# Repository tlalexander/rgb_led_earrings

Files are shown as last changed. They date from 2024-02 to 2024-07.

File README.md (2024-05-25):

# rgb_led_earrings

CAD:
https://cad.onshape.com/documents/09024334f2a397aa5bc58e5a/w/46f4970e419c9b5834fa8bd0/e/3dd3a53ca6818e1934df52f5

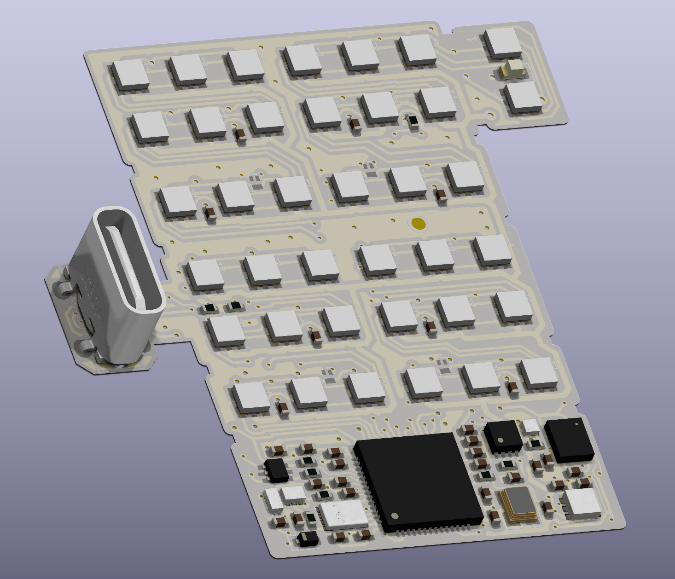
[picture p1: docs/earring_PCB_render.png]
a render of the front of the PCB

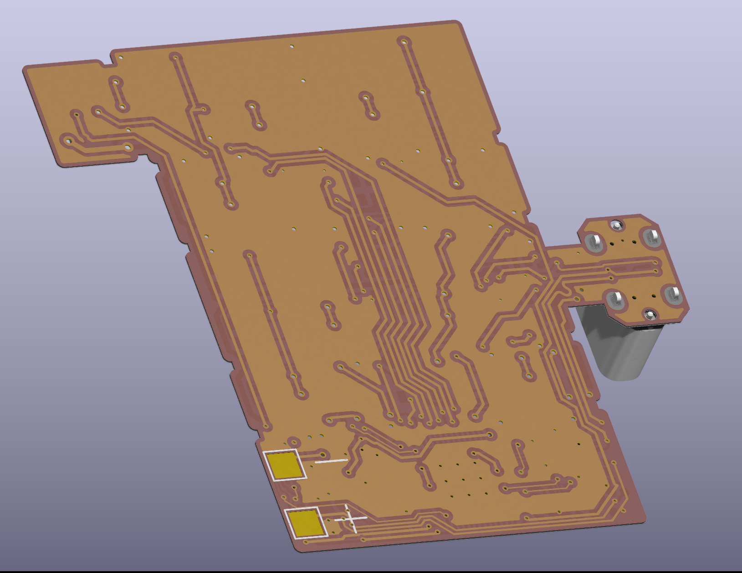
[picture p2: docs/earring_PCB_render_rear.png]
a render of the rear of the PCB


A gentle glow shines from your direction.
A twist, a step, a shimmy.
You move with freedom in your space.
Today is a good day. <3

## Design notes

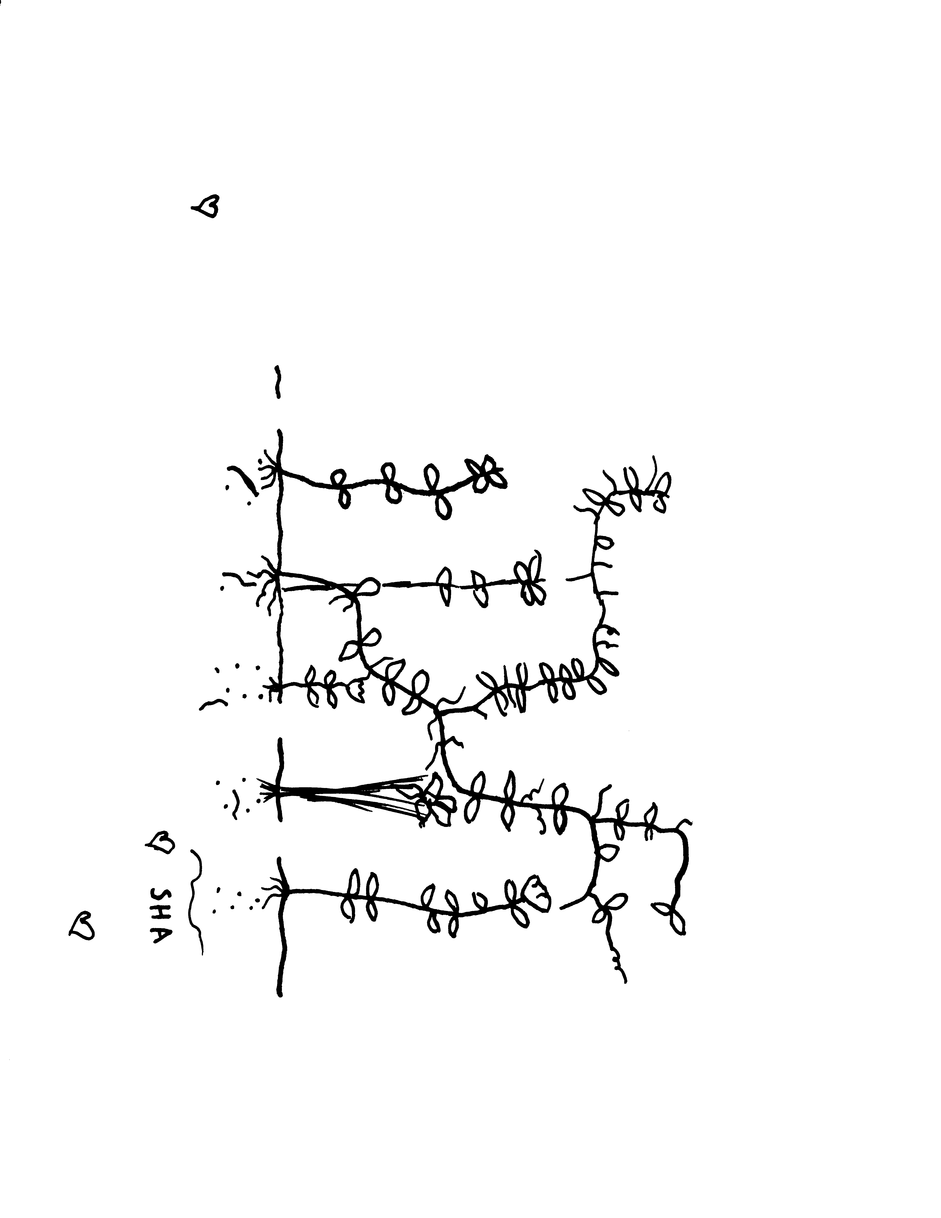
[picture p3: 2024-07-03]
docs/mask_clean_up.png

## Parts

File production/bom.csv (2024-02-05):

Designator | Footprint | Quantity | Value | LCSC Part #
C1, C11, C13, C14, C15, C16, C17, C18, C19, C22, C23, C24, C4, C8, C9 | 0402 | 15 | 100n | C30926
C10, C12, C20, C25, C26, C27, C28, C29, C30, C31, C32 | 0402 | 11 | 1u | C15849
C2, C21, C3, C7 | 0402 | 4 | 10u | C15850
C5, C6 | 0402 | 2 | 20p | C1648
D2 | D_SOD-523 | 1 | D | C4468063
J2 | USB-C-TH_GT-USB-7055 | 1 | USB_C_Receptacle_USB2.0 | C2686963
Q1, Q2, Q3, Q4 | Diodes_DFN1006-3 | 4 | NMOS 20V 0.75A 500mΩ@4.5V | C504098
R1, R5 | 0402 | 2 | 1.1k | C325543
R10 | 0402 | 1 | ~
R2 | 0402 | 1 | 100k | C60491
R3, R4 | 0402 | 2 | 5.1k | C137955
R6, R7 | 0402 | 2 | 27 | C138021
R9 | 0402 | 1 | 510 | C137860
U1 | DFN1608-3_L1.5-W0.8-P0.42-BL-EP | 1 | Magnetic Switch | C879626
U10 | SOT-666 | 1 | USBLC6-2P6 | C2827693
U11, U12, U13, U14, U15, U16, U17, U18, U19, U21, U22, U24, U25, U26, U27, U28, U29, U30, U31, U32, U33, U34, U35, U36, U37, U38, U39, U40, U41, U42, U45, U46, U47, U48, U49, U5, U50, U52 | LED-SK9822-EC20 | 38 | ~
U20 | DFN-8-1EP_2x2mm_P0.5mm_EP0.9x1.5mm | 1 | LGS4056H | C5124109
U3 | RP2040-QFN-56 | 1 | RP2040 | C2040
U4 | IC_W25Q16JVUXIQ_TR | 1 | W25Q16JV | C2843335
U6 | UFDFN-6_1.45x1mm | 1 | Buffer | C7598681
U7 | LGA-14_3x2.5mm_P0.5mm_LayoutBorder3x4y | 1 | LSM6DS3 | C2829074
U8 | DFN1x1 | 1 | ~ | C5884119
U9 | WDFN-6-2x2 | 1 | ~
Y1 | Crystal_SMD_2520-4Pin_2.5x2.0mm | 1 | Crystal_GND24 | C284155

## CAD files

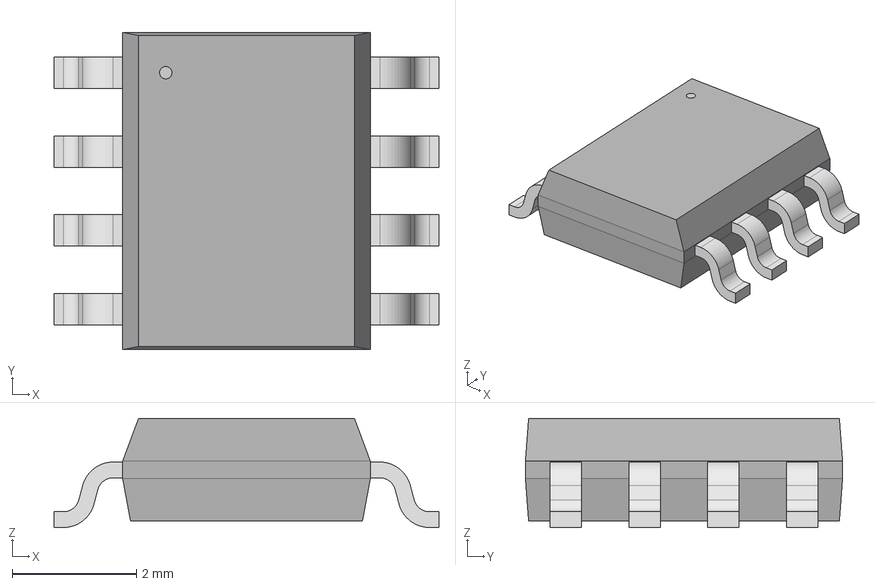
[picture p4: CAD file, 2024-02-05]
parts/2022-10-21_22-39-45/STEP/SOP8SOIC-8_UMW.step
6.20 x 5.11 x 1.75 mm

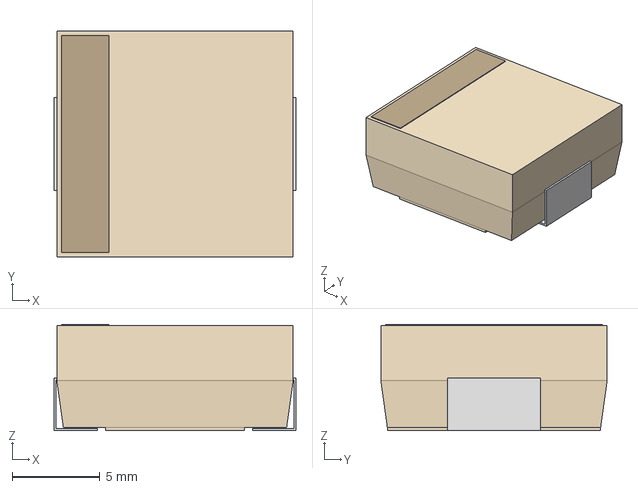
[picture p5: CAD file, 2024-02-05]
parts/2022-11-05_07-16-47/STEP/IND_MWSA1206S_SNL.step
13.8 x 12.9 x 6.04 mm

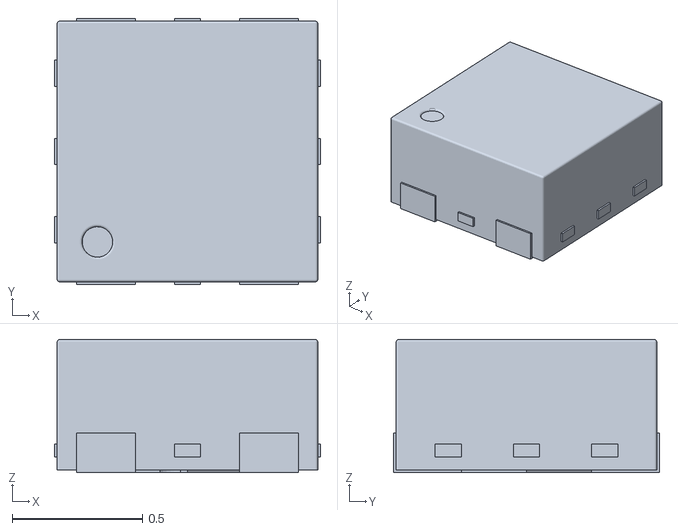
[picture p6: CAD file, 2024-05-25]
parts/DFN-4_L1.0-W1.0-P0.65-BL-EP.obj
1.02 x 1.02 x 0.51

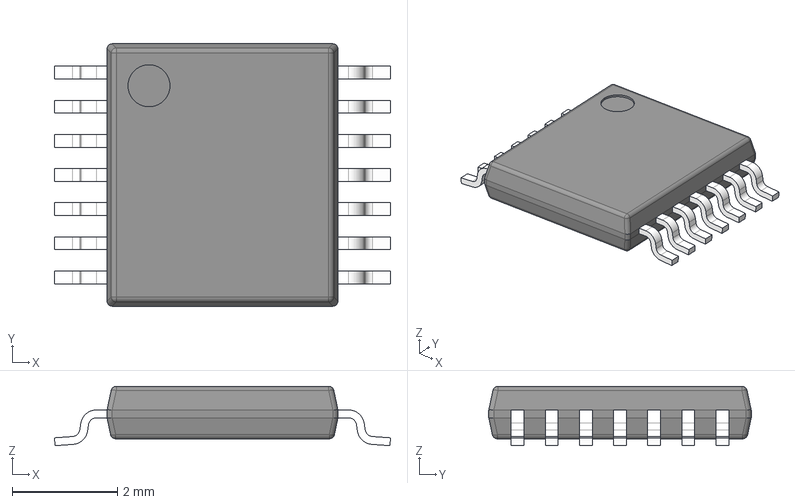
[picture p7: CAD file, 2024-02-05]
parts/STEP/PW0014A.stp
6.40 x 5.00 x 1.13 mm
BODY-TSSOP
LEAD-TSSOP x 14
PIN1

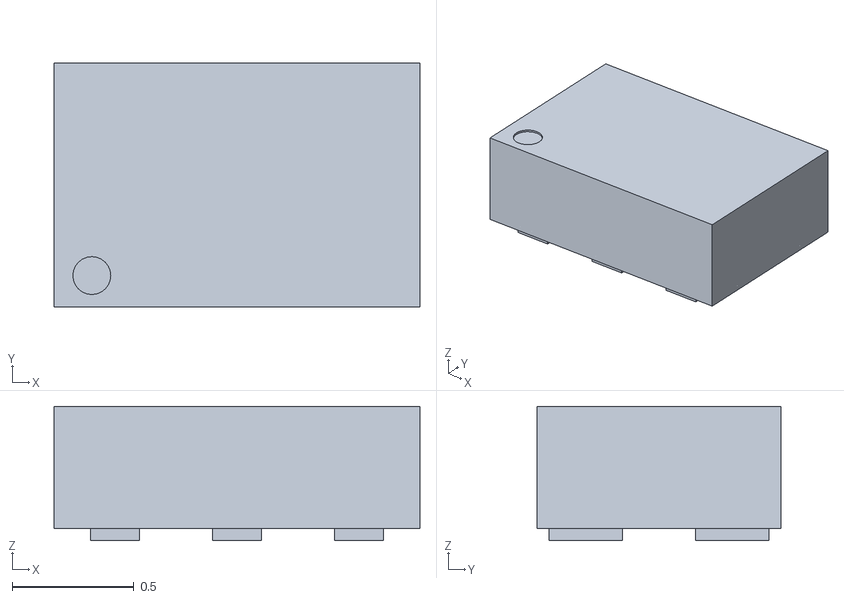
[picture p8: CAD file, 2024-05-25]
parts/SON-6_L1.5-W1.0-P0.50-BL_TI_DRY.obj
1.50 x 1.00 x 0.55

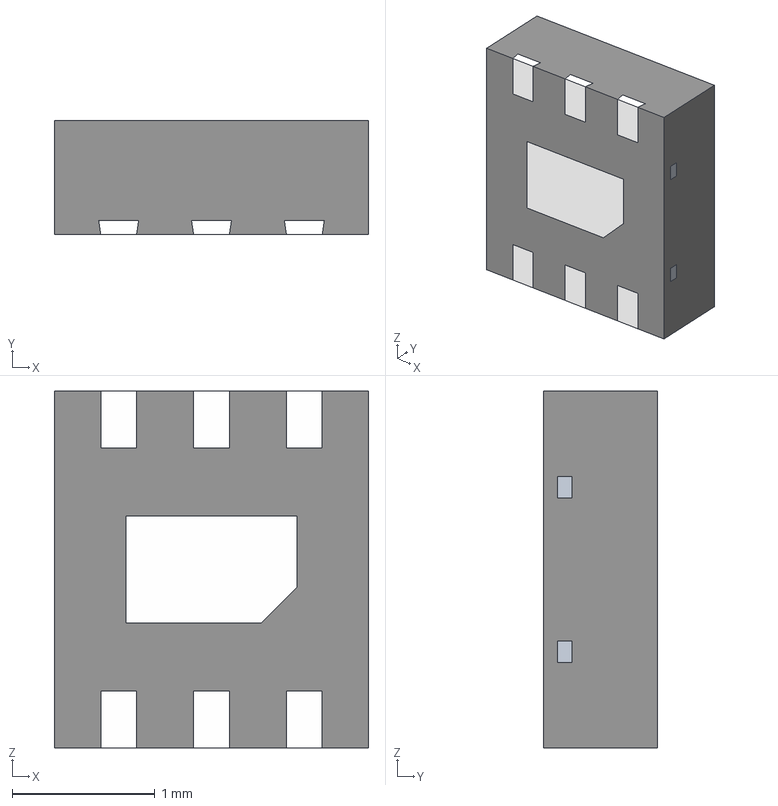
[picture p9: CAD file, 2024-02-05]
parts/STEP/NGF0006A.stp
2.20 x 0.8 x 2.50 mm
BODY_SDB06A_48
MANIFOLD_SOLID_BREP_1871
MANIFOLD_SOLID_BREP_2022
MANIFOLD_SOLID_BREP_2173
MANIFOLD_SOLID_BREP_2324
MANIFOLD_SOLID_BREP_2475
MANIFOLD_SOLID_BREP_2626
MANIFOLD_SOLID_BREP_2777
MANIFOLD_SOLID_BREP_2928
MANIFOLD_SOLID_BREP_3079
MANIFOLD_SOLID_BREP_3230
MANIFOLD_SOLID_BREP_3414

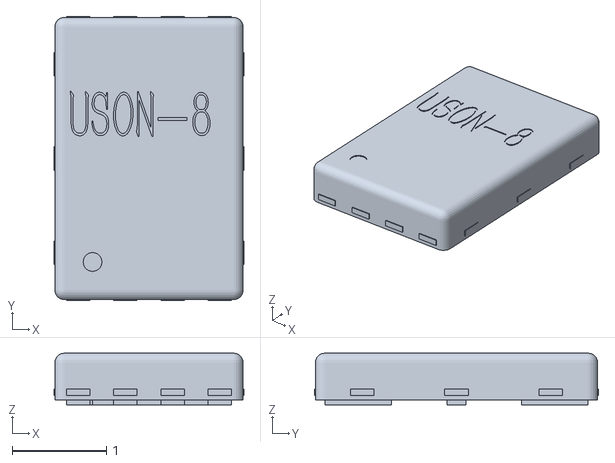
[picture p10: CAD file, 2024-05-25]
parts/USON-8_L3.0-W2.0-P0.50-BL-EP.obj
2.02 x 3.02 x 0.55

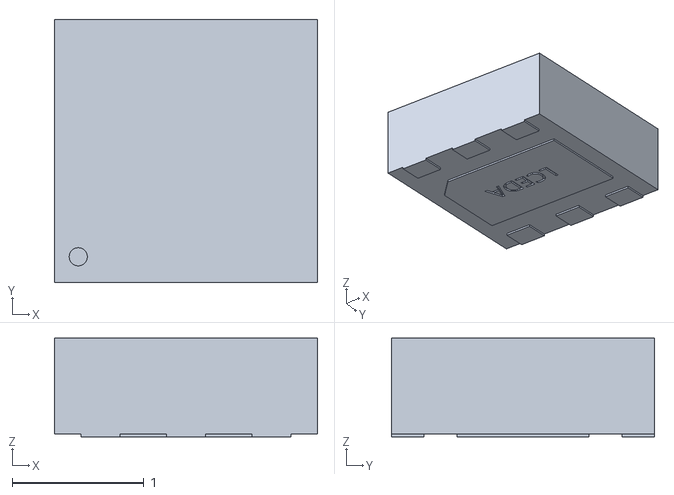
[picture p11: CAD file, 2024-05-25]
parts/WDFN-6_L2.0-W2.0-P0.65-BL-EP-1.obj
2.00 x 2.00 x 0.75

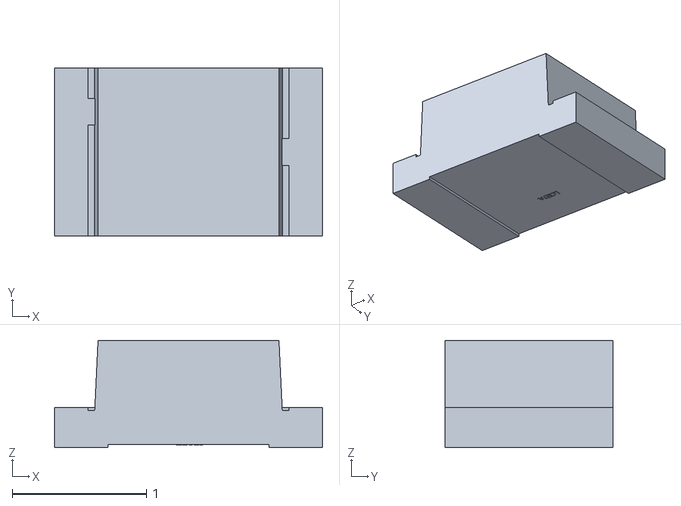
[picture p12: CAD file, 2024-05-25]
parts/OPTO-SMD_SFH3710-Z.obj
2.00 x 1.25 x 0.8

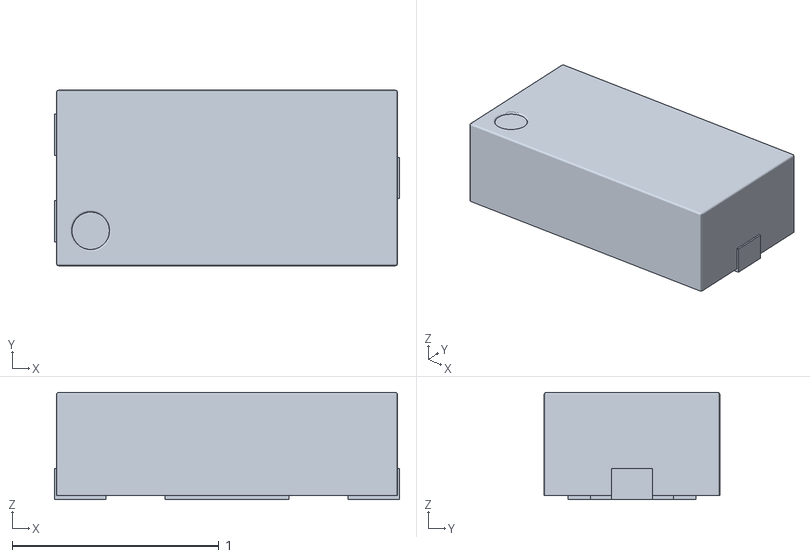
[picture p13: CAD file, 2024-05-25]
parts/DFN1608-3_L1.5-W0.8-P0.42-BL-EP.obj
1.67 x 0.85 x 0.52

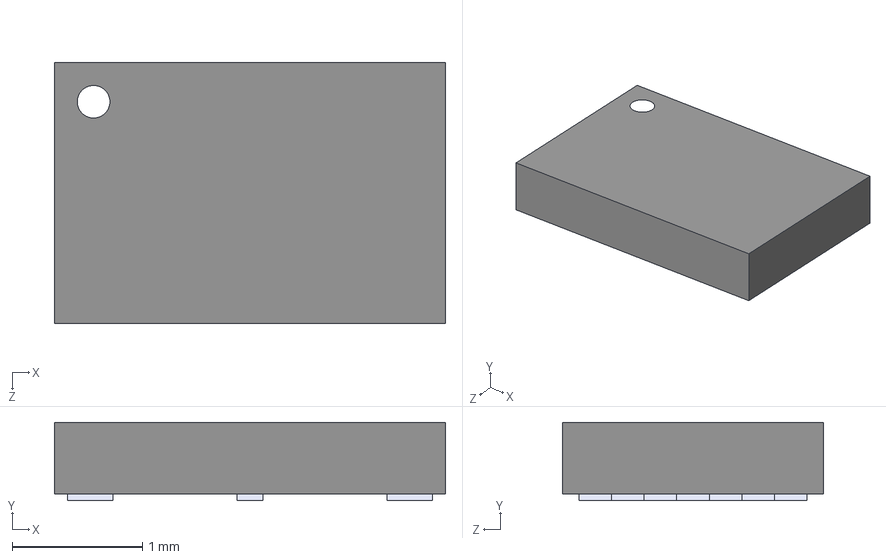
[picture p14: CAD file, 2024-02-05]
parts/W25Q16JVUXIQ_TR.step
3.00 x 0.6 x 2.00 mm

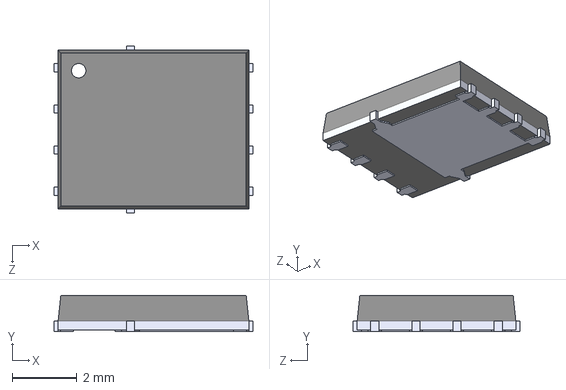
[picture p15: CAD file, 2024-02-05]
parts/PowerPAK-SO8.STEP
6.15 x 1.12 x 5.16 mm

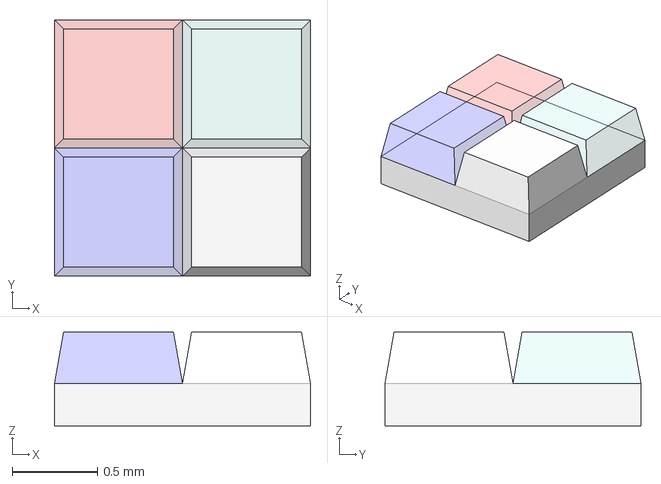
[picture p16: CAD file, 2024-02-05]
parts/sk6812_1.5x1.5mm.step
1.50 x 1.50 x 0.55 mm

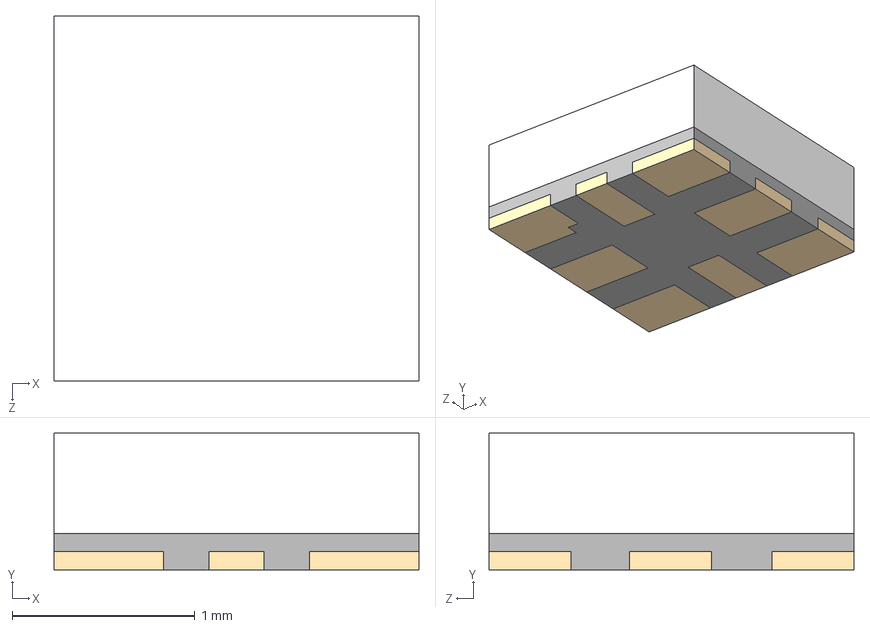
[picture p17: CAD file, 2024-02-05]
parts/APA-102-2020-256-8.STEP
2.00 x 0.75 x 2.00 mm

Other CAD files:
parts/sk6812_opaque.step
parts/DWV0008A.stp
parts/earring_pcb - Flat pattern of pcb.dxf
parts/USB4125-GF-A-0190--3DModel-STEP-56544.STEP
parts/5556416-1.stp
parts/STEP/DWV0008A.stp
parts/USB-C-TH_GT-USB-7055.obj
parts/WDFN-6-2x2.step
parts/sk6812_1.5x1.5_freecad.step

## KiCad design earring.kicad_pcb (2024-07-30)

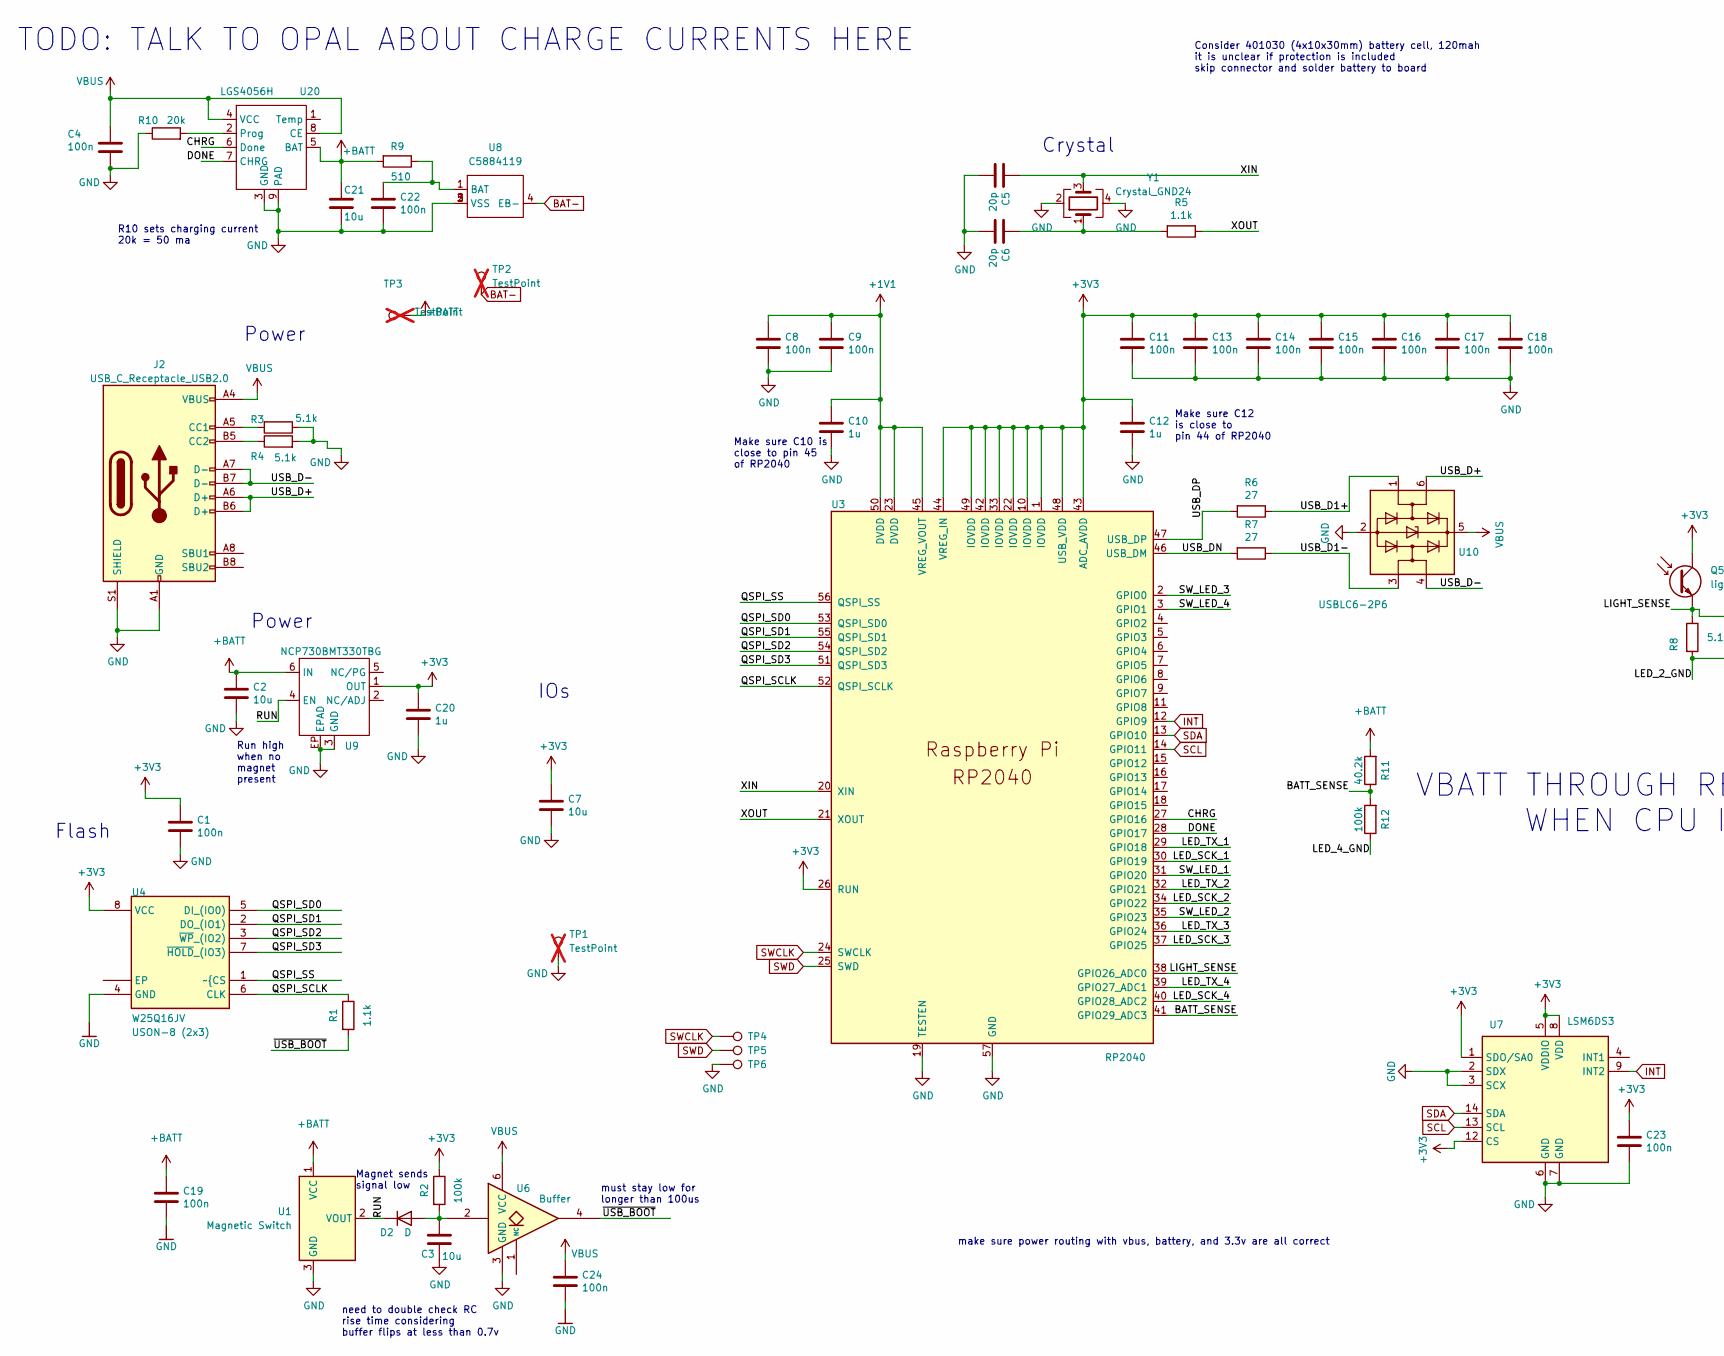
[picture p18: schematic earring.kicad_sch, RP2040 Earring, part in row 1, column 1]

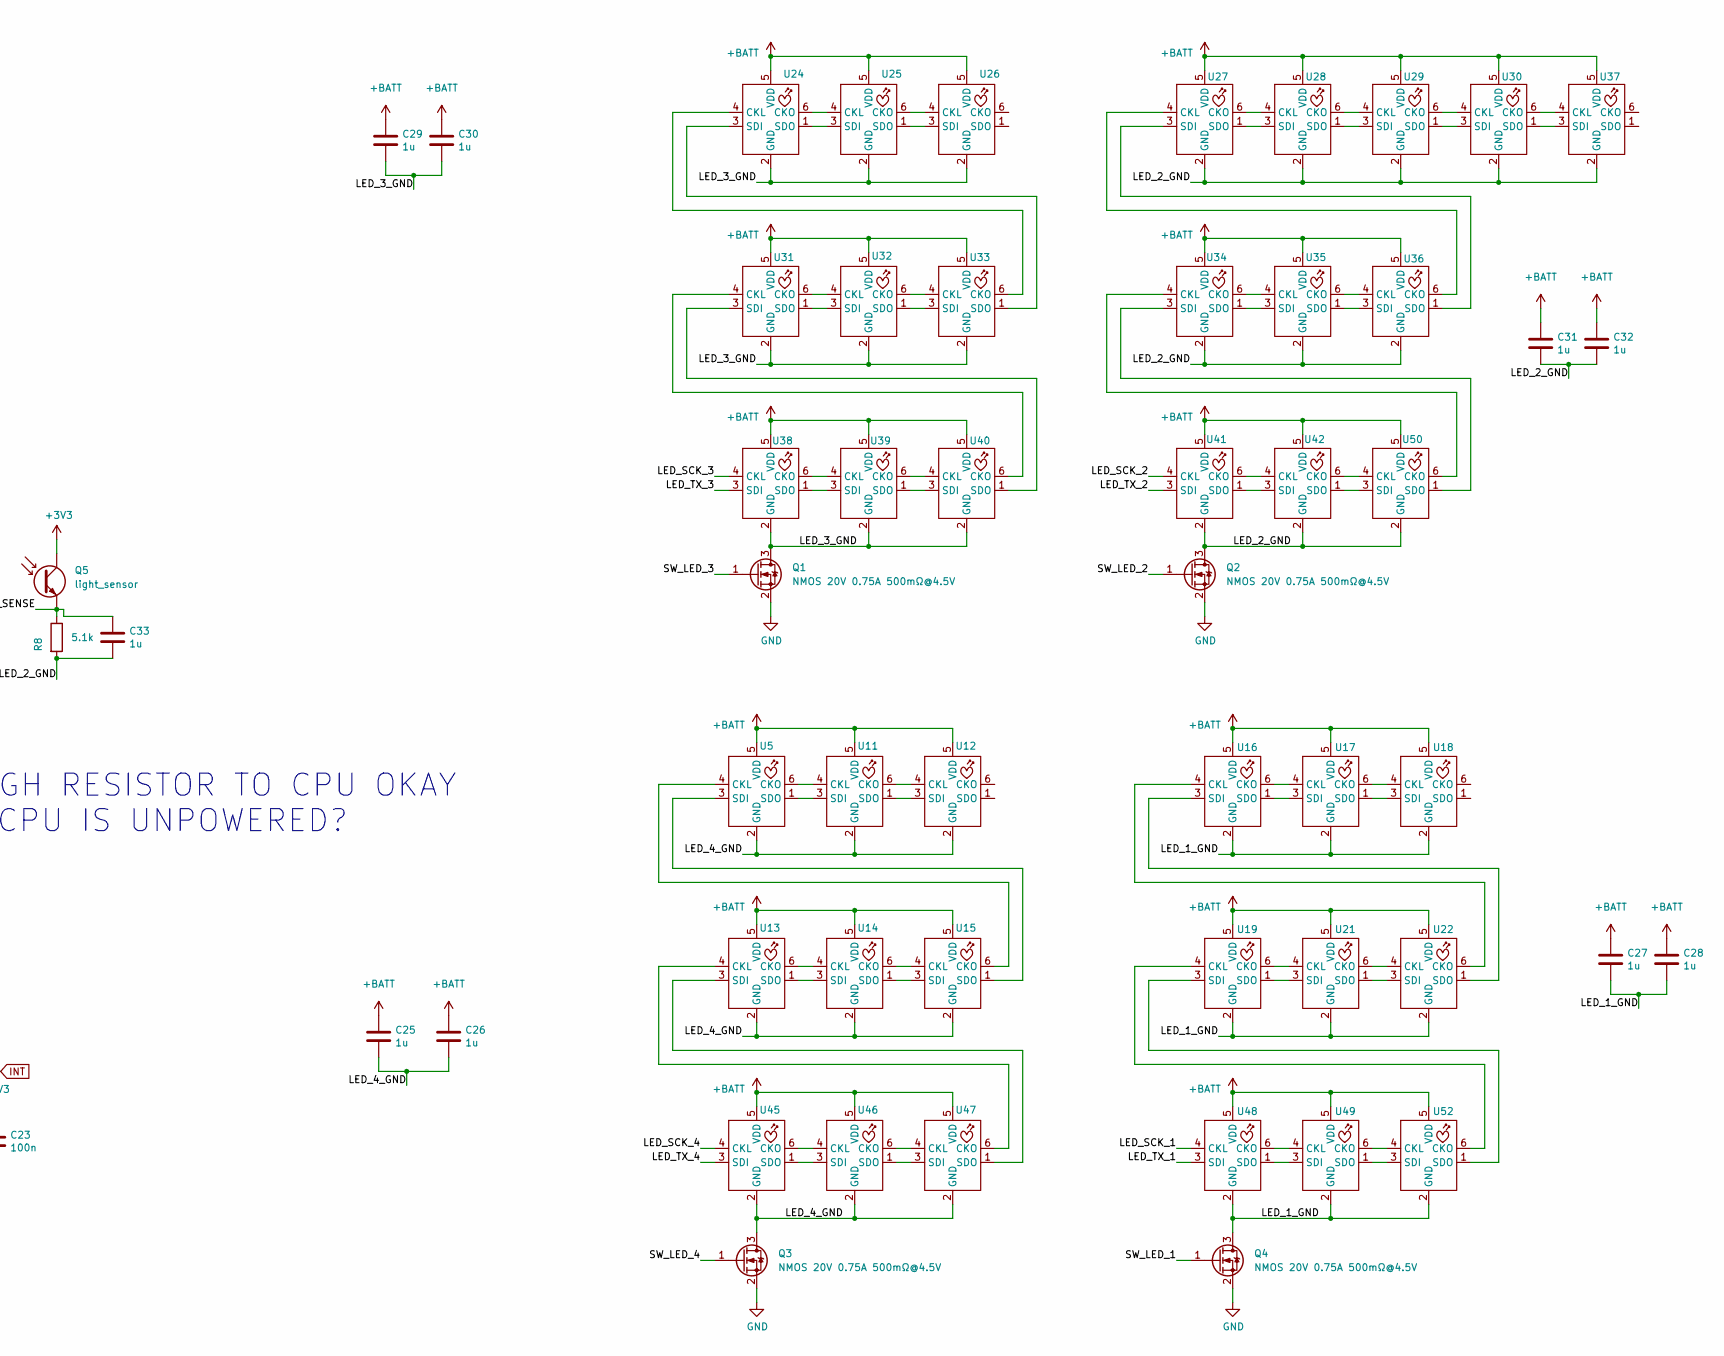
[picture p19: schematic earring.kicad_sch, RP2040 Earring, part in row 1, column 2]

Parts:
C1, C4, C8, C9, C11, C13, C14, C15, C16, C17, C18, C19, C22, C23, C24: 100n; C_0402_1005Metric; LCSC C60474
C2, C3, C7, C21: 10u; C_0402_1005Metric; LCSC C315248
C5, C6: 20p; C_0402_1005Metric; LCSC C107000
C10, C12, C20, C25, C26, C27, C28, C29, C30, C31, C32, C33: 1u; C_0402_1005Metric; LCSC C29266
D2: D; D_SOD-523; LCSC C4468063
J2: USB_C_Receptacle_USB2.0; USB-C-TH_GT-USB-7055; LCSC C2686963
Q1, Q2, Q3, Q4: NMOS 20V 0.75A 500mΩ@4.5V; Diodes_DFN1006-3; LCSC C504098
Q5: light_sensor; LED_0603_1608Metric; LCSC C146233
R1, R5: 1.1k; R_0402_1005Metric; LCSC C325543
R2, R12: 100k; R_0402_1005Metric; LCSC C60491
R3, R4, R8: 5.1k; R_0402_1005Metric; LCSC C25905
R6, R7: 27; R_0402_1005Metric; LCSC C138021
R9: 510; R_0402_1005Metric; LCSC C137860
R10: 20k; R_0402_1005Metric; LCSC C25765
R11: 40.2k; R_0402_1005Metric; LCSC C25893
TP1: TestPoint; TestPoint_Pad_D1.0mm; LCSC C238130; not fitted
TP2, TP3: TestPoint; TestPoint_Pad_2.0x2.0mm; LCSC C238130; not fitted
TP4, TP5, TP6: TestPoint; TestPoint_Pad_1.0x1.0mm
U1: Magnetic Switch; DFN1608-3_L1.5-W0.8-P0.42-BL-EP; LCSC C879626
U3: RP2040; RP2040-QFN-56; LCSC C2040
U4: W25Q16JV; IC_W25Q16JVUXIQ_TR; MPN W25Q16JVUXIQ; LCSC C2843335
U5, U11, U12, U13, U14, U15, U16, U17, U18, U19, U21, U22, U25, U26, U27, U28, U29, U30, U31, U32, U33, U34, U35, U36, U37, U38, U39, U40, U41, U42, U45, U46, U47, U48, U49, U50, U52: LED-SK9822-EC20
U6: Buffer; UFDFN-6_1.45x1mm; LCSC C2864615
U7: LSM6DS3; LGA-14_3x2.5mm_P0.5mm_LayoutBorder3x4y; LCSC C2829074
U8: DFN1x1; LCSC C5884119
U9: NCP730BMT330TBG; WDFN-6-2x2; LCSC C892821
U10: USBLC6-2P6; SOT-666; LCSC C2827693
U20: LGS4056H; DFN-8-1EP_2x2mm_P0.5mm_EP0.9x1.5mm; LCSC C5124109
U24: SK9822-EC20; LED-SK9822-EC20
Y1: Crystal_GND24; Crystal_SMD_2520-4Pin_2.5x2.0mm; LCSC C284155

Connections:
+1V1: C8.1, C9.1, C10.1, U3.23 (DVDD), U3.45 (VREG_VOUT), U3.50 (DVDD)
+3V3: C1.1, C7.1, C11.1, C12.1, C13.1, C14.1, C15.1, C16.1, C17.1, C18.1, C20.1, C23.1, Q5.1, R2.1, U3.1 (IOVDD), U3.10 (IOVDD), U3.22 (IOVDD), U3.26 (RUN), U3.33 (IOVDD), U3.42 (IOVDD), U3.43 (ADC_AVDD), U3.44 (VREG_IN), U3.48 (USB_VDD), U3.49 (IOVDD), U4.8 (VCC), U7.1 (SDO/SA0), U7.5 (VDDIO), U7.8 (VDD), U7.12 (CS), U9.1 (OUT)
+BATT: C2.1, C19.1, C21.1, C25.1, C26.1, C27.1, C28.1, C29.1, C30.1, C31.1, C32.1, R9.2, R11.2, TP3.1, U1.1 (VCC), U5.5 (VDD), U9.6 (IN), U11.5 (VDD), U12.5 (VDD), U13.5 (VDD), U14.5 (VDD), U15.5 (VDD), U16.5 (VDD), U17.5 (VDD), U18.5 (VDD), U19.5 (VDD), U20.5 (BAT), U21.5 (VDD), U22.5 (VDD), U24.5 (VDD), U25.5 (VDD), U26.5 (VDD), U27.5 (VDD), U28.5 (VDD), U29.5 (VDD), U30.5 (VDD), U31.5 (VDD), U32.5 (VDD), U33.5 (VDD), U34.5 (VDD), U35.5 (VDD), U36.5 (VDD), U37.5 (VDD), U38.5 (VDD), U39.5 (VDD), U40.5 (VDD), U41.5 (VDD), U42.5 (VDD), U45.5 (VDD), U46.5 (VDD), U47.5 (VDD), U48.5 (VDD), U49.5 (VDD), U50.5 (VDD), U52.5 (VDD)
/BATT_SENSE: R11.1, R12.2, U3.41 (GPIO29_ADC3)
/CHRG: U3.27 (GPIO16), U20.6 (Done)
/DONE: U3.28 (GPIO17), U20.7 (CHRG)
/LED_1_GND: C27.2, C28.2, Q4.3 (D), U16.2 (GND), U17.2 (GND), U18.2 (GND), U19.2 (GND), U21.2 (GND), U22.2 (GND), U48.2 (GND), U49.2 (GND), U52.2 (GND)
/LED_2_GND: C31.2, C32.2, C33.2, Q2.3 (D), R8.2, U27.2 (GND), U28.2 (GND), U29.2 (GND), U30.2 (GND), U34.2 (GND), U35.2 (GND), U36.2 (GND), U37.2 (GND), U41.2 (GND), U42.2 (GND), U50.2 (GND)
/LED_3_GND: C29.2, C30.2, Q1.3 (D), U24.2 (GND), U25.2 (GND), U26.2 (GND), U31.2 (GND), U32.2 (GND), U33.2 (GND), U38.2 (GND), U39.2 (GND), U40.2 (GND)
/LED_4_GND: C25.2, C26.2, Q3.3 (D), R12.1, U5.2 (GND), U11.2 (GND), U12.2 (GND), U13.2 (GND), U14.2 (GND), U15.2 (GND), U45.2 (GND), U46.2 (GND), U47.2 (GND)
/LED_SCK_1: U3.30 (GPIO19), U48.4 (CKL)
/LED_SCK_2: U3.34 (GPIO22), U41.4 (CKL)
/LED_SCK_3: U3.37 (GPIO25), U38.4 (CKL)
/LED_SCK_4: U3.40 (GPIO28_ADC2), U45.4 (CKL)
/LED_TX_1: U3.29 (GPIO18), U48.3 (SDI)
/LED_TX_2: U3.32 (GPIO21), U41.3 (SDI)
/LED_TX_3: U3.36 (GPIO24), U38.3 (SDI)
/LED_TX_4: U3.39 (GPIO27_ADC1), U45.3 (SDI)
/LIGHT_SENSE: C33.1, Q5.2, R8.1, U3.38 (GPIO26_ADC0)
/QSPI_SCLK: R1.1, U3.52 (QSPI_SCLK), U4.6 (CLK)
/QSPI_SD0: U3.53 (QSPI_SD0), U4.5 (DI_(IO0))
/QSPI_SD1: U3.55 (QSPI_SD1), U4.2 (DO_(IO1))
/QSPI_SD2: U3.54 (QSPI_SD2), U4.3 (~WP_(IO2))
/QSPI_SD3: U3.51 (QSPI_SD3), U4.7 (~HOLD_(IO3))
/QSPI_SS: U3.56 (QSPI_SS), U4.1 (~{CS)
/RUN: D2.1 (K), U1.2 (VOUT), U9.4 (EN)
/SW_LED_1: Q4.1 (G), U3.31 (GPIO20)
/SW_LED_2: Q2.1 (G), U3.35 (GPIO23)
/SW_LED_3: Q1.1 (G), U3.2 (GPIO0)
/SW_LED_4: Q3.1 (G), U3.3 (GPIO1)
/USB_D1+: R6.1, U10.1 (I/O1)
/USB_D1-: R7.1, U10.3 (I/O2)
/USB_D+: J2.A6 (D+), J2.B6 (D+), U10.6 (I/O1)
/USB_D-: J2.A7 (D-), J2.B7 (D-), U10.4 (I/O2)
/USB_DN: R7.2, U3.46 (USB_DM)
/USB_DP: R6.2, U3.47 (USB_DP)
/XIN: C5.1, U3.20 (XIN), Y1.3
/XOUT: R5.1, U3.21 (XOUT)
/~USB_BOOT: R1.2, U6.4
BAT-: TP2.1, U8.4 (EB-)
GND: C1.2, C2.2, C3.2, C4.2, C5.2, C6.2, C7.2, C8.2, C9.2, C10.2, C11.2, C12.2, C13.2, C14.2, C15.2, C16.2, C17.2, C18.2, C19.2, C20.2, C21.2, C22.2, C23.2, C24.2, J2.A1 (GND), J2.A12 (GND), J2.B1 (GND), J2.B12 (GND), J2.S1 (SHIELD), Q1.2 (S), Q2.2 (S), Q3.2 (S), Q4.2 (S), R3.1, R4.2, R10.1, TP1.1, TP6.1, U1.3 (GND), U3.19 (TESTEN), U3.57 (GND), U4.4 (GND), U6.3 (GND), U7.2 (SDX), U7.3 (SCX), U7.6 (GND), U7.7 (GND), U8.2 (VSS), U8.3 (VSS), U8.5 (VSS), U9.3 (GND), U9.EP (EPAD), U10.2 (GND), U20.3 (GND), U20.9 (PAD), Y1.2, Y1.4
INT: U3.12 (GPIO9), U7.9 (INT2)
unnamed: C6.1, R5.2, Y1.1
unnamed: C3.1, D2.2 (A), R2.2, U6.2
unnamed: J2.A5 (CC1), R3.2
unnamed: J2.B5 (CC2), R4.1
unnamed: C22.1, R9.1, U8.1 (BAT)
unnamed: U5.6 (CKO), U11.4 (CKL)
unnamed: U11.6 (CKO), U12.4 (CKL)
unnamed: U5.1 (SDO), U11.3 (SDI)
unnamed: U11.1 (SDO), U12.3 (SDI)
unnamed: U13.4 (CKL), U47.6 (CKO)
unnamed: U13.6 (CKO), U14.4 (CKL)
unnamed: U13.3 (SDI), U47.1 (SDO)
unnamed: U13.1 (SDO), U14.3 (SDI)
unnamed: U14.6 (CKO), U15.4 (CKL)
unnamed: U14.1 (SDO), U15.3 (SDI)
unnamed: U5.4 (CKL), U15.6 (CKO)
unnamed: U5.3 (SDI), U15.1 (SDO)
unnamed: U16.4 (CKL), U22.6 (CKO)
unnamed: U16.6 (CKO), U17.4 (CKL)
unnamed: U16.3 (SDI), U22.1 (SDO)
unnamed: U16.1 (SDO), U17.3 (SDI)
unnamed: U17.6 (CKO), U18.4 (CKL)
unnamed: U17.1 (SDO), U18.3 (SDI)
unnamed: U19.4 (CKL), U52.6 (CKO)
unnamed: U19.6 (CKO), U21.4 (CKL)
unnamed: U19.3 (SDI), U52.1 (SDO)
unnamed: U19.1 (SDO), U21.3 (SDI)
unnamed: R10.2, U20.2 (Prog)
unnamed: U21.6 (CKO), U22.4 (CKL)
unnamed: U21.1 (SDO), U22.3 (SDI)
unnamed: U24.4 (CKL), U33.6 (CKO)
unnamed: U24.6 (CKO), U25.4 (CKL)
unnamed: U24.3 (SDI), U33.1 (SDO)
unnamed: U24.1 (SDO), U25.3 (SDI)
unnamed: U25.6 (CKO), U26.4 (CKL)
unnamed: U25.1 (SDO), U26.3 (SDI)
unnamed: U27.4 (CKL), U36.6 (CKO)
unnamed: U27.6 (CKO), U28.4 (CKL)
unnamed: U27.3 (SDI), U36.1 (SDO)
unnamed: U27.1 (SDO), U28.3 (SDI)
unnamed: U28.6 (CKO), U29.4 (CKL)
unnamed: U28.1 (SDO), U29.3 (SDI)
unnamed: U29.6 (CKO), U30.4 (CKL)
unnamed: U29.1 (SDO), U30.3 (SDI)
unnamed: U30.6 (CKO), U37.4 (CKL)
unnamed: U30.1 (SDO), U37.3 (SDI)
unnamed: U31.4 (CKL), U40.6 (CKO)
unnamed: U31.6 (CKO), U32.4 (CKL)
unnamed: U31.3 (SDI), U40.1 (SDO)
unnamed: U31.1 (SDO), U32.3 (SDI)
unnamed: U32.6 (CKO), U33.4 (CKL)
unnamed: U32.1 (SDO), U33.3 (SDI)
unnamed: U34.4 (CKL), U50.6 (CKO)
unnamed: U34.6 (CKO), U35.4 (CKL)
unnamed: U34.3 (SDI), U50.1 (SDO)
unnamed: U34.1 (SDO), U35.3 (SDI)
unnamed: U35.6 (CKO), U36.4 (CKL)
unnamed: U35.1 (SDO), U36.3 (SDI)
unnamed: U38.6 (CKO), U39.4 (CKL)
unnamed: U38.1 (SDO), U39.3 (SDI)
unnamed: U39.6 (CKO), U40.4 (CKL)
unnamed: U39.1 (SDO), U40.3 (SDI)
unnamed: U41.6 (CKO), U42.4 (CKL)
unnamed: U41.1 (SDO), U42.3 (SDI)
unnamed: U42.6 (CKO), U50.4 (CKL)
unnamed: U42.1 (SDO), U50.3 (SDI)
unnamed: U45.6 (CKO), U46.4 (CKL)
unnamed: U45.1 (SDO), U46.3 (SDI)
unnamed: U46.6 (CKO), U47.4 (CKL)
unnamed: U46.1 (SDO), U47.3 (SDI)
unnamed: U48.6 (CKO), U49.4 (CKL)
unnamed: U48.1 (SDO), U49.3 (SDI)
unnamed: U49.6 (CKO), U52.4 (CKL)
unnamed: U49.1 (SDO), U52.3 (SDI)
SCL: U3.14 (GPIO11), U7.13 (SCL)
SDA: U3.13 (GPIO10), U7.14 (SDA)
SWCLK: TP4.1, U3.24 (SWCLK)
SWD: TP5.1, U3.25 (SWD)
VBUS: C4.1, C24.1, J2.A4 (VBUS), J2.A9 (VBUS), J2.B4 (VBUS), J2.B9 (VBUS), U6.6 (VCC), U10.5 (VBUS), U20.4 (VCC), U20.8 (CE)

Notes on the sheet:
Make sure C10 is close to pin 45 of RP2040
Consider 401030 (4x10x30mm) battery cell, 120mah it is unclear if protection is included skip connector and solder battery to board
Power
Crystal
R10 sets charging current 20k = 50 ma
need to double check RC rise time considering buffer flips at less than 0.7v
IOs
TODO: TALK TO OPAL ABOUT CHARGE CURRENTS HERE
must stay low for longer than 100us
VBATT THROUGH RESISTOR TO CPU OKAY WHEN CPU IS UNPOWERED?
Magnet sends signal low
Make sure C12 is close to pin 44 of RP2040
make sure power routing with vbus, battery, and 3.3v are all correct
Run high when no magnet present
Flash

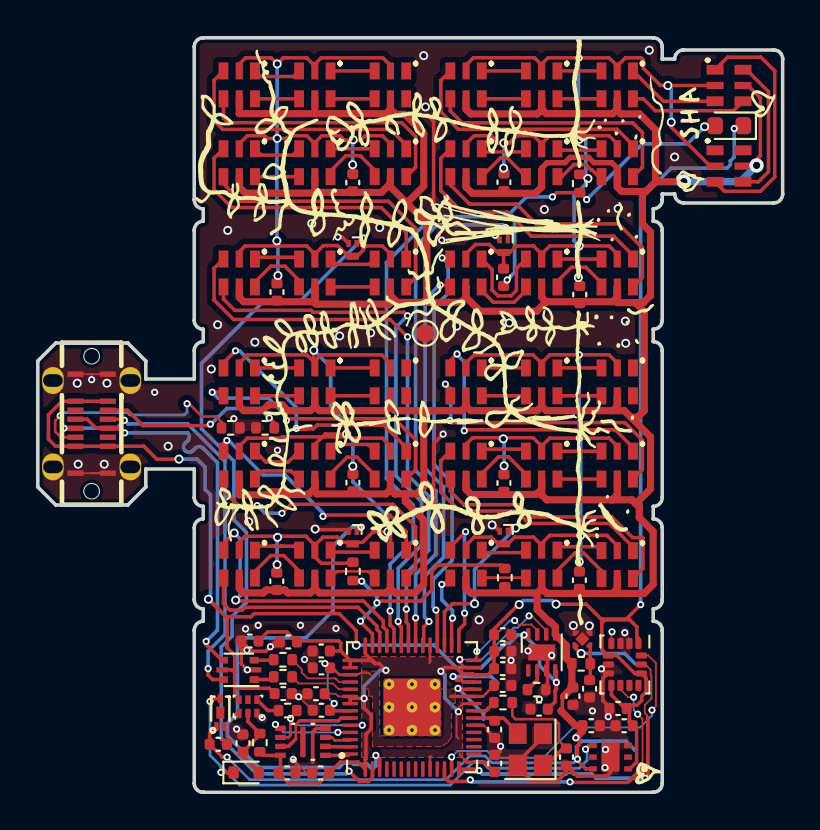
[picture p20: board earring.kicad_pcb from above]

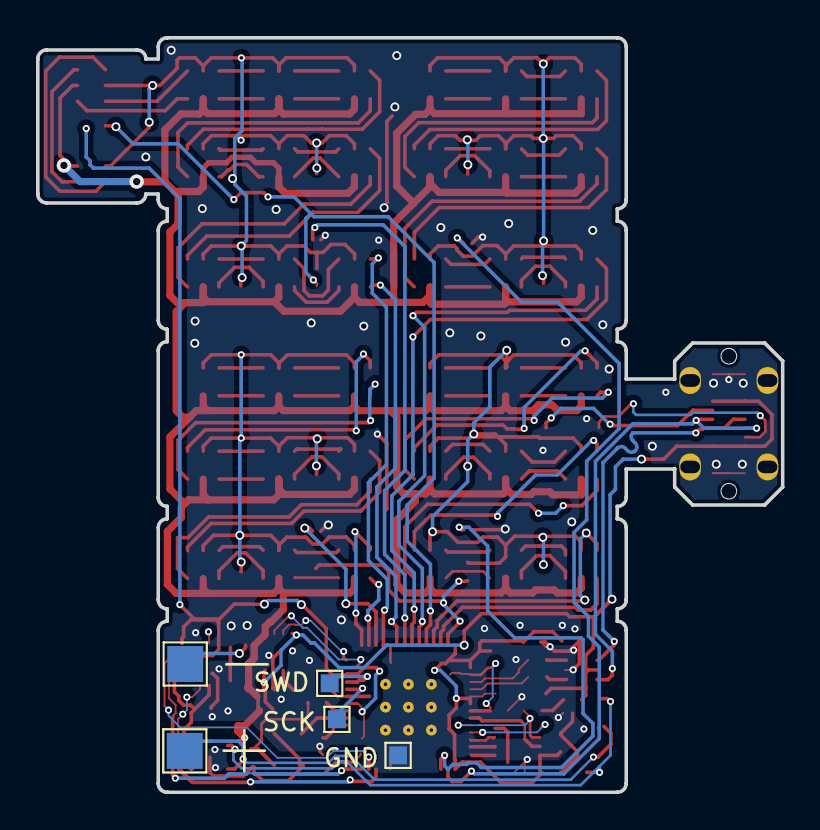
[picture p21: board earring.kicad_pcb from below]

Board: 2 copper layers, 41.4 x 41.9 mm, 106 parts (5 on the bottom side), 121 nets.

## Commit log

2024-02-07 Updated files, nearly complete. Added stiffener layer.
    [earring.kicad_pcb, earring.kicad_sch]
2024-05-25 Add light sensor, add more 3d models.
    [DFN-4_L1.0-W1.0-P0.65-BL-EP.obj, DFN1608-3_L1.5-W0.8-P0.42-BL-EP.obj, OPTO-SMD_SFH3710-Z.obj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]
2024-07-03 added silkscreen, debug contacts, and voltage monitoring
    [earring.kicad_pcb, earring.kicad_sch]
2024-07-30 update stiffener layer
    [earring.kicad_pcb, earring.kicad_sch]

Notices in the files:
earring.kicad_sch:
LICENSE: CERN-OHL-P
